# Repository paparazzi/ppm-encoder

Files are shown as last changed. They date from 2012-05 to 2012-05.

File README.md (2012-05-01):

ppm-encoder
===========

PPM Encoder board: http://paparazzi.enac.fr/wiki/ATmega_PPM_Encoder_Board

Author: hendrix (Chris Efstathiou)

Comments:  This software is FREE. Use it at YOUR OWN RISK.

PPM Encoder Hardware
--------------------
  - There are currently three revisions of the PPM Encoder board based around the ATMega168 mcu
  - The DIYDrones/3DRobotics version is an additional and different fourth hardware version based on this work
  - The code is/should be compatible with other ATMega8 series mcus, (known to work with the ATMega328)
  - The first board revision uses the internal RC oscillator of the mcu; this can cause timing accuracy issues
  - Later versions use an external 16MHz crystal/oscillator and provide cleaner, more stable output
  - Setting the fuses correctly for your hardware design is very important!

PPM Encoder Software
--------------------
  - The software is user configurable in the servo2ppm_settings.h file.
  - The software must be configured for the correct clock frequency and mcu in the makefile (or possibly the settings file).
  - The compiler for the software is avr-gcc.
  - Ideally, the software should be compiled using the version of avr-gcc included with WinAVR 2007 build 1221, available for download on sourceforge: http://sourceforge.net/projects/winavr/files/WinAVR/20071221/
  - Since this is windows software, you can run it on a windows box, a windows virtual machine or in wine (which seems to work fine). If using wine, call make with "wine" as a prefix: $ wine make (arguments).
  - The software can be easily loaded with avrdude using a supported programmer. Depending on which version you have, you may need to update avrdude.conf to include your mcu (i.e. if you have a 328).
  - There is a bootloader available if no programmer is available (but the bootloader will need to be loaded once with a programmer prior to use).
  - The fuses on your mcu must be carefully set. This can be done with avrdude. See below for correct fuse settings.

Fuse Settings
-------------
  - These settings may not work in all cases, depending on your board.
  - VERIFY BEFORE CHANGING FUSES ON YOUR MCU, OR YOU MAY BRICK IT! (especially the low fuse)
  - An online avr fuse calculator may help: http://www.engbedded.com/fusecalc
  - Low fuse has the same functions for the mega 328 and mega 168
  - High fuse sets sets the bootsize on 328 and the bodlevel in 168
  - Extended fuse sets the bodlevel only on 328 but it sets the bootsize on 168i
  - If you aren't using the bootloader, the fuses should still work fine, though feel free to disable the bootloader reset vector

**Low Fuse (same for 168 and 328, with or without bootloader):**
  - **0xDF** : 16Mhz External Oscillator (typically 0xFF on DIYDrones board)
  - **0xC2** : 8Mhz Internal RC Oscillator

**High Fuse:**
  - **0xDC** : for 168
  - **0xD8** : for 328

**Extended Fuse:**
  - **0xF8** : for 168
  - **0xFC** : for 328

**Note:** some numerical values refer to fuses containing undefined bits (set to '1' here). Depending on the target device these fuse bits will be read either as '0' or '1'. Verification errors will occur if the values are read back with undefined bits set to '0'.
 - For the 168: Everything is fine if the values read from the device are either the same as programmed, or the following values (undefined set to '0'): Extended: 0x00.
 - For the 328: Everything is fine if the values read from the device are either the same as programmed, or the following values (undefined set to '0'): Extended: 0x04

(Above note from http://www.engbedded.com/fusecalc)

Bootloader
----------
 - The bootloader is found in sw/bootloader.
 - To compile the bootloader, edit the MCU and F_CPU part of the makefile to match your hardware.
 - The memory offset will be automatically selected and assumes the fuses are set as described above
 - To compile the bootloader after editing the makefile:

    $ make

PPM Encoder
-----------
 - The ppm encoder source is found in sw/ppm_encoder.
 - Before compiling, edit the makefile for the appropriate clock frequency to match your hardware. You may also need to specify the path to the compiled bootloader .hex if you are trying to load the bootloader at the same time as the ppm encoder program.
 - To compile for the atmega328p (the makefile defaults to the 328):

    $ make

 - To compile for the atmega168:

    $ make mcu=atmega168

Uploading the Code
------------------

 - To upload the code to your board with a programmer, either directly call avrdude, or adjust the parameters in the makefile and call make program:

    $ avrdude -C /PATH/TO/ALTERNATE/avrdude.conf -c YOUR_PROGRAMMER_NAME -P YOUR_PROG_PORT -p YOUR_MCU -U flash:w:ppm_encoder_v4_3.hex:i

 - Check the avrdude help for more details and for how to check and write fuses (be careful). The makefile in sw/ppm_encoder can also be used to set fuses with make fuse_read to check and make fuse_write to set (make sure MCU and F_CPU are set correctly). The alternate avrdude.conf file might be needed if your version of avrdude does not have your mcu type defined (i.e. macports avrdude can direct to the Arduino 1.0 avrdude.conf if needed)

Some more example commands would be nice!

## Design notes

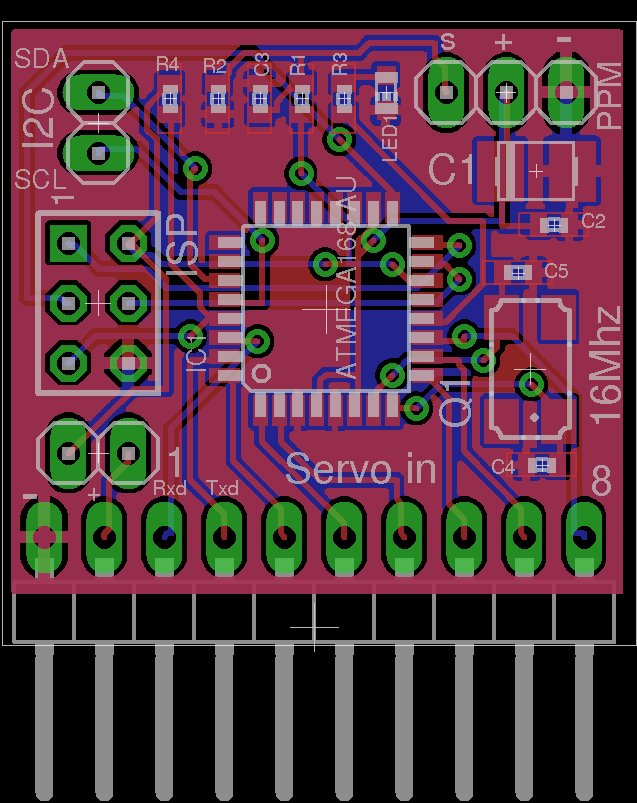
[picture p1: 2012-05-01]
hw/pcb_v3/ppm_encoder_crystal_v3.png

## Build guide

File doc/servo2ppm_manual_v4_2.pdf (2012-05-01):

# USER MANUAL

# PPM ENCODER BOARD

## (ATMEGA168)

### VERSION 4.2 (Firmware)

Created by Hendrix and Moa

3rd August 2009

### Table of Contents

JP1 JUMPER

FOR THOSE THAT MIGHT MAKE THE PPM ENCODER FROM SCRATCH:

FAILSAFE CONSIDERATIONS

THE PAPARAZZI “RADIO.XML" FILE

The places of interest for the “Bootloader procedure” are highlighted in Yellow on the

3rd August 2009 | 1

### INTRODUCTION

This software is FREE. Use it at your own risk.
This software and application comes without any guarantee of any kind.
You can modify the code and everything else as you please.

The whole project is based around the ATMEL ATMEGA168 AVR processor and all timing is done within interrupts so accuracy and stability is optimized
It is now also possible to select the PPM waveform shift, negative or positive.

Please use the above mentioned processor otherwise you may need to change/modify the source files of the project. The source code knows what chip you use from the device selected in the makefile.

Have in mind that the Paparazzi autopilot is a very complex system and you must pay attention to details

### OVERVIEW

You can use the throttle channel or any other channel to put the Paparazzi autopilot into "AUTO2" or “HOME” mode depending on the airframe settings.
This is effected by the PPM Encoder shutting down the PPM signal.

Basically you can connect any Rx channel to any PPM Encoder channel with the following provisions:

The RC receiver's throttle channel must be connected to channel 3 of the PPM Encoder as it is used as a rc signal lost indicator if the setup procedure has not be performed - otherwise any channel can be used if you execute the setup procedure

You can set the point where you want the PPM output to be turned off using the setup procedure else the default is that any servo pulse above ~2025 microseconds will shut down the PPM output thus force the Paparazzi autopilot into the "AUTO2" or “HOME” mode.

Make sure that your throttle channel's servo pulse does not exceed the PPM shut down threshold during normal operation by adjusting the EPA or whatever you call the servo travel limiter.
Only during loss of the RC signal when the receiver enters the failsafe mode should the throttle channel, or any other channel used as a Tx signal lost indication, be allowed to exceed this threshold (say 2100 microseconds).

The PPM board will cut the PPM output when the receiver goes into failsafe and set the throttle channel or any other channel if the setup procedure has been performed, to the extreme position.
This is done in order to simulate a traditional PPM receiver like the ones the Paparazzi designers used.

The extreme channel value used for indicating the signal loss to the PPM Encoder is not passed to the Paparazzi autopilot since the PPM output will be cut off when this extreme servo position is detected.

If the PPM board is set to continue to produce a PPM output, by not setting up the receiver to output this extreme servo position upon Tx signal loss means that your only option is to set the failsafe value of the receiver “MODE” channel to ”AUTO2” so the plane can enter the “AUTO2” mode
This method is not recommended for the following reasons:

If, upon loss of signal, all channels stay legitimate and the “MODE” channel indicates “AUTO2” then Paparazzi will enter “AUTO2” mode. Paparazzi will not be aware of the signal loss condition and will believe the pilot has com-manded the AUTO2 mode. Should the signal be reestablished with the Tx switch still in “Manual” mode then Paparazzi will faithfully switch to “MAN-UAL” mode with no pilot interaction.

Paparazzi, by design, manages the mode switching if it sees a loss of signal but with this configuration, the PPM Encoder hides the loss of signal so Paparazzi cannot manage mode switching safely.

Also be aware that some receivers failsafe due to low battery voltage (e.g.Futaba 7C) which can be reset (for 30 seconds) by selecting minimum throttle. Care must be exercised not to zero the throttle accidentally or pur-posely without considering the “MODE” switch. position. Again you could be put in command of the aircraft by a method other than using the “MODE” switch.

There are some receivers made by Futaba that output their servo pulses in a peculiar way.
One known Futaba Rx outputs the servo channels in the following order: 7,6,1,2,3,4,5
with channel 6 overlapping with channel 1. That should not cause any problem to the PPM encoder

Sometimes you may notice on some 2.4 Ghz systems that the ppm encoder takes some time
(1-3 seconds) to produce a PPM output.
This is because some 2.4 Ghz systems need to perform a hand shaking between the Transmitter and the receiver before they start producing a pulse at their throttle channel.

### FIRMWARE VERSIONS

RECEIVER TYPES AND THE PPM ENCODER BEHAVIOR

Version 3.8 firmware / Normal PPM receiver
The PPM Encoder will stop producing any PPM pulses when the Tx signal is lost thus setting the autopilot to "HOME" or "AUTO2" mode depending on the airframe settings.

Version 3.8 firmware / Receiver with failsafe settings on all channels
The user must set the failsafe for the "MODE" channel to 2000 microseconds so the autopilot can enter the "AUTO2" only mode when signal is lost.
This firmware is old and you should upgrade to version 4.00.

Version 3.9 firmware / Normal PPM Receiver
The PPM Encoder will stop producing any PPM pulses thus setting the autopilot the autopilot to "HOME" or "AUTO2" mode depending on the airframe settings.

Version 3.9 firmware / Receiver with failsafe settings on all channels or only the throttle channel. The user must make sure that the throttle channel will go above 2020 microseconds when the receiver looses the Tx signal but not during normal operation so when the receiver goes in to failsafe (loss of Tx signal) the PPM Encoder will cut the PPM output thus set the autopilot to "HOME" or "AUTO2" mode depending on the airframe settings.

Of course he can leave the throttle channel's failsafe setting to below 2000 microseconds and set the "MODE" channel's failsafe setting to 2000 microseconds thus force the autopilot in to "AUTO2" but this is not recommended.

Version 4.x firmware / Receiver with failsafe settings on all channels or only the throttle channel. The user must make sure that the throttle channel will go above 2025 microseconds when the receiver looses the Tx signal but not during normal operation so when the receiver goes into failsafe (loss of Tx signal) the PPM Encoder will cut the PPM output thus set the autopilot to "HOME" or "AUTO2" mode depending on the airframe settings.

In this version the user can also use a different than the throttle channel as a Tx lost indicator
and also setup the point where the PPM output will by cut off by using a simple setup procedure.

Of course he can leave the throttle channel's failsafe setting to below 2000 microseconds and set the "MODE" channel's failsafe setting to 2000 microseconds thus force the autopilot in to "AUTO2" but this is not recommended.

UNSUITABLE RECEIVERS

A receiver with no failsafe capabilities at least on the throttle channel (ch3) or also does not cut the servo pulses after a Tx signal loss but keeps the last good values is NOT SUITABLE FOR USE WITH THE PPM ENCODER.

### IMPORTANT THINGS TO WATCH FOR:

JP1 Jumper

The jumper JP1 has been included to provide some flexibility in the way you power the receiver, servos and PPM Encoder.

Often the power for the receiver, servos and PPM Encoder will come from the autopilot board. In this case JP1 should be in place.

If the receiver and any servos directly connected to the receiver get power from a separate/additional power source and the autopilot +5V is also connected to the PPM Encoder via the PPM connector - THEN YOU MUST REMOVE jumper JP1.
This will isolate the autopilot power supply from the separate receiver power supply.
Failure to remove JP1 will likely damage the autopilot's +5v switching regulator!

+5V provided
from autopilot+5V Not provided

from autopilot

Power supplied from Receiver and Servos Remove JP1JP1 in place

# Power NOT supplied from Receiver and Servos JP1 in place

For those that might make the PPM Encoder from scratch:

1. Before operating the PPM encoder, remember to clear the check mark for the

"CKDIV8" fuse. This is the only fuse that needs to be modified on a new ATMEGA168.
The ATMEGA168 is shipped with the internal oscillator selected as the clock source but with the "CKDIV8" fuse checked it is running at 1Mhz and not the 8Mhz we require.
2. If you decide to also use the bootloader make sure that you also check these three fuses:
1) BOOTRST, 2)BOOTSZ0, 3)BOOTSZ1.

Those 3 fuses tell the mcu to move the reset vector to the bootloader address and to reserve all 2048 bytes of bootloader memory space.

Failsafe considerations

1. When a receiver has failsafe mode this means that the servo pulses will not stop when the Tx signal is lost thus the encoder will always see valid servo signals
2. If you use a receiver with failsafe then remember to set the receiver's failsafe value for the throttle to above 2025 microseconds (2050 for example) so the PPM Encoder can simulate a traditional PPM receiver by shutting down the PPM signal.
You can alter the 2025 microsecond limit by executing the setup procedure.

Alternatively (not recommended, see above) set the "MODE" channel failsafe value to ~2000 microseconds so the autopilot can go to "AUTO2" mode when the received RC signal is lost or set.

3. If the receiver failsafe of the "MODE" channel is left at 1000 or 1500 microseconds and the throttle channel's failsafe setting does not exceed the 2025 microsecond limit then the aircraft is not protected and you will likely crash and loose the plane for the following reasons.
a) Paparazzi will stay in Manual mode because the MODE channel still commands this.
b) PPM Encoder will maintain a good PPM output and so Paparazzi will not enter AUTO2 or HOME mode as the signal is still considered good.
4. If the receiver only provides "hold" on the last good servo signal received it is not suitable for use with this encoder as it will prohibit the autopilot entering the "AUTO2" mode or initiate a lost signal condition by ceasing to pass a PPM signal to the autopilot.

This circuit was designed for use with:

a) Good quality receivers with full failsafe capabilities those days like the Multiplex IPD, the PCM range of receivers or the newer 2.4GHz ones.
b) Receivers that can be set to simply turn off the servo pulses when the Tx signal is lost
c) Simple PPM receivers that cannot maintain good servo pulses when reception is bad.

The Paparazzi “radio.xml" file

1. You must use a "radio.xml" file that contains 8 channels no matter how many channels your receiver has.

2. The PPM Encoder now dictates the number of channels and the PPM timing.
3. The reset_max value inside the radio.xml file should be more than 13000 microseconds.
Here is an example of a working "radio.xml" file for my Royal Evo 12 and my MC4000 with the "MODE" channel being channel 7:

<!DOCTYPE radio SYSTEM "radio.dtd">
<radio name="RE12" data_min="800" data_max="2200" sync_min="5000" sync_max="15000"> <channel ctl="C" function="ROLL" min="950" neutral="1500" max="2050" average="0"/> <channel ctl="B" function="PITCH" min="950" neutral="1500" max="2050" average="0"/> <channel ctl="D" function="THROTTLE" min="950" neutral="950" max="2050" average="0"/> <channel ctl="A" function="YAW" min="950" neutral="1500" max="2050" average="0"/> <channel ctl="E" function="FLAPS" min="950" neutral="1500" max="2050" average="0"/> <channel ctl="F" function="GAIN1" min="950" neutral="1500" max="2050" average="1"/> <channel ctl="G" function="MODE" min="950" neutral="1500" max="2050" average="1"/> <channel ctl="H" function="GAIN2" min="950" neutral="1500" max="2050" average="1"/> </radio>

If you want the "MODE" channel to be channel 5 just change the order of the lines:

<!DOCTYPE radio SYSTEM "radio.dtd">
<radio name="RE12" data_min="800" data_max="2200" sync_min="5000" sync_max="15000"> <channel ctl="C" function="ROLL" min="950" neutral="1500" max="2050" average="0"/> <channel ctl="B" function="PITCH" min="950" neutral="1500" max="2050" average="0"/> <channel ctl="D" function="THROTTLE" min="950" neutral="950" max="2050" average="0"/> <channel ctl="A" function="YAW" min="950" neutral="1500" max="2050" average="0"/> <channel ctl="G" function="MODE" min="950" neutral="1500" max="2050" average="1"/> <channel ctl="E" function="FLAPS" min="950" neutral="1500" max="2050" average="0"/> <channel ctl="F" function="GAIN1" min="950" neutral="1500" max="2050" average="1"/> <channel ctl="H" function="GAIN2" min="950" neutral="1500" max="2050" average="1"/> </radio>
4. If you want you can change the channel assignment of your Tx or Rx at anytime. Just make sure that the channel functions, as they are connected at the PPM Encoder, match the order in the radio.xml file.

An example:
Say you have an eight channel receiver that has channels 1,2,3,4,8 connected to the PPM Encoder with channel 8 being the "MODE" channel and suddenly you want to swap the receiver with a 6 channel one. You now don’t have a receiver channel 8 but the solution is very simple.
- You must connect channels 1,2,3,4 as before
- Connect any one of the remaining channels (say Rx channel 5) to channel 8 of the PPM encoder.

- You next assign the "MODE" switch on your transmitter to channel 5.
- You should not change anything in the radio.xml file as servo position 8 on the PPM Encoder was already known to be the MODE channel by Paparazzi.

The PPM Encoder dictates the channel order you see in the "radio.xml" file and not the receiver servo channels. If, as in the above example, channel 5 of the receiver is the "MODE" channel and this channel is connected to servo connector/position 8 of the PPM encoder, then Paparazzi autopilot will see the "MODE" channel as being channel 8 no matter what channel you use at your transmitter or receiver side.

5. The PPM Encoder is built to output a Futaba style PPM signal which differs from that of all other brands including JR. Paparazzi must be set to expect a Futaba style PPM signal.
- Locate the following line in the airframe file (correct)
"ap.CFLAGS += -DRADIO_CONTROL -DRADIO_CONTROL_TYPE=RC_FUTABA"

If your definition reads as follows (incorrect)
"ap.CFLAGS += -DRADIO_CONTROL -DRADIO_CONTROL_TYPE=RC_JR " modify it to be the same as the correct line above with FUTABA in place of JR.

Alternatively you can set the definition "RC_PPM_OUTPUT_TYPE" to 1.

It does not matter what make of receiver or transmitter you have since the PPM Encoder controls all parameters of the PPM waveform.

### HOW TO TEST THE BOARD

Here we test that the PPM Encoder is basically working.

Refer to the image of the board for the points referred to in this “How to test the Board” procedure”. They are highlighted in Magenta .

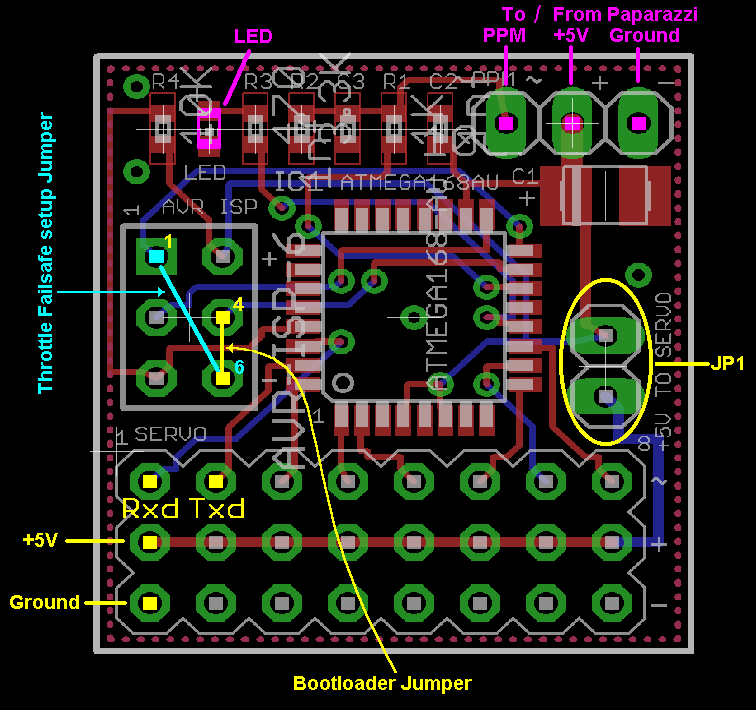
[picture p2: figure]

For this test you may initially leave the "MODE" channel of the receiver disconnected from the PPM Encoder. It can be connected later during the procedure.

SAFETY FIRST

- Start with all airplane and Tx power off
- Ensure the JP1 jumper is set correctly as per “IMPORTANT THINGS TO WATCH FOR”

REMOVE THE PROPELLER OR DICONNECT THE MOTOR CABLES !!!

- Connect the encoder to the receiver and autopilot.
Please verify the integrity of all connections to the autopilot and from the receiver to the PPM Encoder board. The PPM output pin header has the ground near the PCB corner, the positive 5 volts to the middle pin and the PPM output is the pin near the 402 sized components (C2, R1, C3 etc.).
- Power up the airplane with the Tx powered off.
The LED should be on constantly without blinking.
- Power On the RC transmitter
The LED should start to blink with a rate 3 times per second (that is 3Hz)
The LED blinking at 3Hz means that the internal timing is correct, that the board sees all of the incoming receiver servo pulses and that the PPM waveform generator is on and working.
- Confirm that the servos move when you move the sticks.
- Next disconnect a channel from the receiver (just unplug it) and see if the led blinks slower now at 1 time per second (1Hz).
That means that one or more of the servo signals are lost and that the PPM output is off.
- Now remove power from the plane, connect the “MODE” channel from the RC receiver to the PPM Encoder board if you haven't done it already.
- Ensure you have assigned the Transmitter Mode switch to the appropriate channel.
- Power on the RC transmitter again first and then the airplane.
The PPM encoder's led should blink fast at a rate of ~3Hz and you should be able to switch between “MANUAL', “AUTO1' and “AUTO2” using the RC transmitter's switch that you have assigned to be the mode change switch.

You can tell in what mode you are in by looking at the GCS screen.

VERY IMPORTANT

The following test ensures the PPM Encoder stops the PPM signal when a failsafe receiver goes into failsafe.
(You can perform this test later if you are going to use the THROTTLE FAILSAFE SETUP procedure)
- Switch to “MANUAL” mode
- Move the throttle stick to:
a. Minimum if you have a Futaba transmitter
b. Maximum for all other transmitter brands
c. To the side you selected during the “THROTTLE FAILSAFE SETUP” if you have performed it.
- Adjust the EPA of this throttle stick's side to maximum so the led changes it's blinking rate from 3Hz to 1Hz when you move the throttle stick to the extreme min or max position depending on what brand you have.
- Set this position as the receiver failsafe position for the throttle channel.
You will be able to see the led changing it's flashing rate when you move the throttle stick.
- Now return the EPA to normal in order to make sure that this extreme throttle servo pulse cannot occur during normal operation but only when the receiver goes in to failsafe.

The above steps are required in order to make the PPM Encoder simulate a traditional PPM receiver. The PPM board will cut the PPM output when the receiver goes into failsafe and moves the throttle channel to the extreme position (past 2020 microseconds) exactly like a traditional PPM receiver would.

### HOW TO ENTER THE THROTTLE FAILSAFE SETUP

Here we set up the Throttle Failsafe value. The PPM Encoder is being taught a throttle channel pulse width that, beyond which, will indicate that the Rx is in failsafe mode.

Refer to the image of the board for the points referred to in this procedure”.
They are highlighted in Cyan

If you want to set a channel other than the throttle channel to be the Tx signal lost indicator then you must disconnect all other receiver channels except the desired one from the PPM Encoder and then proceed to complete the setup procedure described below.

If only one channel of the receiver is connected to the PPM Encoder during power up for the setup procedure, then this channel is selected as the Tx signal lost indicator and the PPM shut down threshold can be adjusted for this channel. It can be any channel you want.

If more than one channel of the receiver is connected to the PPM Encoder during power up for the setup procedure then the default channel will be used. This is the Throttle Channel (#3 of the PPM encoder) with a threshold of 2025 microseconds.

This is done in order to enable the user to execute the setup procedure with out disconnecting
the ppm encoder from the system if the default setting of using channel 3 (the throttle channel)
is acceptable.

SAFETY FIRST

- Remove power from the plane
- Ensure the JP1 jumper is set correctly as per “IMPORTANT THINGS TO WATCH FOR”

REMOVE THE PROPELLER OR DICONNECT THE MOTOR CABLES !!!

- Ground pin 1 of the ISP header (Connect Pin 1 to Pin 6 of the ISP header) using a small piece of wire with 2 female pin connectors.
- Stop! ……Do not power up the plane and the PPM board just yet.
- Power up the transmitter

Make sure that the throttle EPA for the throttle side you select in the next step is not set to maximum because you will need a little extra later on (about 7% more). The actual threshold will be set at 25 microseconds above the recorded value if the value recorded was above 1500 microseconds or 25 microseconds below the recorded value if the value recorded was below 1500 microseconds.

In other words the threshold where the PPM output is cut off will be set 25 microseconds above or below the recorded value depending which side of the throttle stick you have selected.

- Set the throttle stick to the end position you want, say at the min throttle position.
This position will be set as the extreme value that can happen during normal operation.
A bit beyond this position is the value you will subsequently set into the Receiver as the failsafe setting
- Then power up the PPM board by connecting the battery to the airplane.
The LED on the PPM board will light solid and when the setup is finished it will start to flash with 1Hz rate and a duty cycle of:
- 100ms ON – 900ms OFF if the setup is successful and with a rate of 1Hz
- 900ms ON – 100ms OFF duty cycle (almost solid on) if the setup failed
(the opposite of when the setup was successful).

If the setup failed (highly unlikely) then check the connections and repeat the setup procedure after a power cycle.

- If the setup was successful then remove power from the PPM board
- Remove the grounding connector from pin 1 of the ISP header.
- Power up again normally, you should see the led flash at 3Hz as usual.
- Test to see if the LED changes it's blinking frequency to 1Hz by adjusting the transmitter throttle EPA of the side you selected during setup to maximum and then moving the throttle stick to the end point you had selected during the setup procedure.
The LED should change it's blinking frequency to 1Hz
- Move the throttle stick back towards the center again.
The LED should change it's blinking frequency back to 3Hz
- Next set this extreme position (the LED should blink with 1 Hz rate) as the receiver failsafe position for the throttle channel.
- Now return the EPA to normal in order and make sure that this extreme throttle servo pulse cannot occur during normal operation. (3Hz blinking at all Throttle positions)
- Finally check that the PPM board changes the led frequency to 1Hz when you switch off the transmitter thus forcing the receiver to enter the failsafe mode.

The above steps are required in order to make the PPM Encoder simulate a traditional PPM receiver. The PPM board will cut the PPM output exactly like a traditional PPM receiver would when a failsafe capable receiver goes into failsafe and moves the throttle channel to the extreme position.

If you do not perform this setup procedure then the default value will be used which is to cut the PPM output when the throttle channel's servo pulse goes above 2025 microseconds.

You can change the default value defined in the “servo2PPM_settings.h” file to suit your needs
but you will need to recompile the source code of the PPM Encoder.

### ABOUT THE BOOTLOADER

The whole project is based around the ATMEL AVR processor and specifically the ATMEGA168. Please use the above mentioned processor otherwise you may need to change/modify the source files of the project.
I have tested the bootloader with other processors and it worked well right out of the box but I can't guarantee anything.
If you want to use the bootloader (recommended so later you can update the firmware without using an AVR programmer) you can use the "app+bootloader.hex" file to flash both the servo2PPM and the bootloader code at once. Alternatively you can first flash the the PPM_encoder_ver_x_x.hex file with the "erase chip before flashing" option of the avrstudio flashing utility turned on and then flash the "bootloader.hex file but this time with the "erase chip before flashing" option turned off
(ie do not erase the chip before you flash the "bootloader.hex" file).
- NOTE: Read carefully the later section from the Mega168 datasheet on Boot Lock Bits.

BEFORE ENTERING THE BOOTLOADER DISCONNECT EVERYTHING FROM THE PPM ENCODER BOARD !!!

The places of interest for the “Bootloader procedure” are highlighted in | Yellow | on the board image
- Make sure that everything (receiver, tiny or TWOG) is disconnected from the PPM Encoder board including power
- Place a jumper between pin 4 and pin 6 (ground) of the ISP header.
- Prepare the FTDI cable
The +5 volts that will power the PPM Encoder board will come from the +5 volts of the FTDI cable so you need to make a cable that will connect the FTDI's +5v,Rxd,Txd and Ground to the PPM encoder's +5v, Rxd, Txd and Ground.

The +5 volts and Ground of the FTDI cable are connected to any of the PPM Encoder board’s servo input +5 volt and ground pins.

The serial pins for connecting the FTDI cable to the PPM Encoder board are the signal pins of servos 1 and 2 . Servo1=Rxd, Servo2=Txd as depicted on the picture of the board.

- NOTE: these must be connected crossed to the FTDI cable
ie. Servo 1 signal pin to FTDI Txd and servo 2 signal pin to FTDI Rxd.
- You can then reset the PPM Encoder board as needed by removing the jumper JP1 that is normally used to feed power to the servo header.
- Wait for ~2 seconds and replace the jumper again on JP1 in order to restore power to the board.

In order to upload the file needed, reset the PPM Encoder board by power cycling it making sure that the connection with the terminal program like "HyperTerminal is already opened and connected
at 9600 bps 8 bits, no parity, 1 stop bit, no flow control and carriage return (CR) as terminator of the line.
After power cycling (reset) the PPM Encoder board you should see the prompt "ATH=help >" on your screen.
- Type "ATWF" using capital or small or mixed letters and hit enter.
Now the "C" character will start to fill the screen which means that you must start the X modem CRC transfer from your terminal program.
- Select the Xmodem type of file transfer, then select the file to be uploaded ("PPM_encoder_ver_x_x.bin") and click the send button or whatever your terminal program uses.
Be carefull "Xmodem 1K" IS NOT THE SAME!!!
Usually “Xmodem CRC” is referred as plain "Xmodem".

Then the transfer window of your program will show up telling you the transfer progress and after the transfer is hopefully complete and successful the window will automatically close and you will
see the message “update successful” at the terminal 's screen.

The bootloader commands are:

ATWF = write flash.
ATWE = write Eeprom.
ATI = Display version information about the bootloader and the PPM Encoder firmware ATRB = Read boot lock fuses.
ATRL = Read the low fuses.
ATRH = Read the high fuses.
ATRE = Read the extended fuses.
ATWB = Write or modify the boot lock fuses

For the PPM Encoder firmware version to be displayed using the “ATI” command the PPM Encoder firmware must run at least once in order to register it's version info into the EEPROM.
That means that if you want to be absolutely sure which version you are about to use after a firmware upgrade then
- power off
- remove the jumper from pins 4 and 6 of the ISP header,
- power on again so the PPM Encoder software can run (No need to connect anything to the PPM Encoder board)
- power off the board, install the jumper to pins 6 and 4 and power on again.
Now the “ATI” command will show something like "Servo2PPM V4.00".

Pay particular attention to the ATWB command as it can render the PPM Encoder useless and then only a flash erase and programming of the board again will make the PPM Encoder work again.

The fuse bytes are presented with binary form for example 00000010 = 2

If you attempt to modify the boot lock fuses you need to issue a command like this: ATWB11111011 + ENTER

The above command will program the BLB02 fuse.

I recommend to leave the boot lock bits as they are and not play with the “ATWB” command at all as the bootloader code is already protecting the bootloader's flash memory space.

### SETTING THE BOOT LOCK BITS

USING THE ATWLxxxxxx BOOTLOADER COMMAND.
BOOT LOCK BIT programming (BLB12, BLB11, BLB02, BLB01, LB2 and LB1)

To set the Boot Loader Lock bits and General Lock bits using the bootloader first examine the table below.

Enter the command ATWLxxxxxx and press enter.
The xxxxxx are the binary presentation of lockbits 5,4,3,2,1 and 0 Bits 7 and 6 are omitted since you cannot program them.

Examples

ATWL11011111
= the boot lock bit 5 will be programmed (BLB12)

ATWL1111101
= the boot lock bit 1 will be programmed (LB2)

ATWL1111110
= the boot lock bit 0 will be programmed (LB1)

So if bits 5..0 in R0 are cleared (zero), the corresponding Boot Lock bit or General Lock bit will be programmed.

“1” means not programmed, “0” means programmed

Be careful with the boot lock bits.

BOOT LOCK PROTECTION MODE TABLES
Below are two tables with the functionality of the boot lock bits of the ATMEGA168.

Boot Lock Bit0 Protection Modes (Application Section)(1)

Table 26-2.
BLB0 Mode | BLB02 | BLB01 | Protection
1 | 1 | 1 | No restrictions for SPM or LPM accessing the Application section.
2 | 1 | 0 | SPM is not allowed to write to the Application section.
3 | 0 | 0 | SPM is not allowed to write to the Application section, and LPM executing from the Boot Loader section is not allowed to read from the Application section. If Interrupt Vectors are placed in the Boot Loader section, interrupts are disabled while executing from the Application section.
4 | 0 | 1 | LPM executing from the Boot Loader section is not allowed to read from the Application section. If Interrupt Vectors are placed in the Boot Loader section, interrupts are disabled while executing from the Application section.

Boot Lock Bit1 Protection Modes (Boot Loader Section)(1)

Table 26-3.
BLB1 Mode | BLB12 | BLB11 | Protection
1 | 1 | 1 | No restrictions for SPM or LPM accessing the Boot Loader section.
2 | 1 | 0 | SPM is not allowed to write to the Boot Loader section.
3 | 0 | 0 | SPM is not allowed to write to the Boot Loader section, and LPM executing from the Application section is not allowed to read from the Boot Loader section. If Interrupt Vectors are placed in the Application section, interrupts are disabled while executing from the Boot Loader section.
4 | 0 | 1 | LPM executing from the Application section is not allowed to read from the Boot Loader section. If Interrupt Vectors are placed in the Application section, interrupts are disabled while executing from the Boot Loader section.

Note: 1. “1” means un-programmed, “0” means programmed

Have fun.
Chris

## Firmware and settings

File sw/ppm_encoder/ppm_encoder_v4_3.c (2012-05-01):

/*********************************************************************************************************
 Title  :   C  file for the rc ppm encoder (servo2ppm_v4_3.c)
 Author:    Chris Efstathiou
 E-mail:    hendrix at vivodinet dot gr
 Homepage:  ........................
 Date:      07/Feb/2010
 Compiler:  AVR-GCC with AVR-AS
 MCU type:  ATmega168
 Comments:  This software is FREE. Use it at your own risk.
*********************************************************************************************************/


/********************************************************************************************************/
/*                                   PREPROCESSOR DIRECTIVES                                            */
/********************************************************************************************************/


#include <avr/io.h>
#include <avr/interrupt.h>
#include <avr/wdt.h>
#include <avr/eeprom.h>
#include <inttypes.h>
#include "servo2ppm_settings.h"




/********************************************************************************************************/
/*             Normaly you shouldn't need to change anything below this line but who knows?             */
/********************************************************************************************************/

#if defined(__AVR_ATmega168__) || defined(__AVR_ATmega328P__)

#define RC_SERVO_PORT                 D   /* The port for the servo pulse input. */

#define RC_LED_PORT                   B  /* The port for the PPM waveform and the led. */
#define RC_LED_PIN                    0  /* The led indicator pin. */

#define RC_PPM_PORT                   B
#define RC_PPM_PIN                    2  /* The PPM waveform output pin */

#define RC_SETUP_PORT                 B
#define RC_SETUP_PIN                  4

#define RC_TIMER0_TIMSK               TIMSK0 /* Timer0 registers */
#define RC_TIMER0_TIFR                TIFR0
#define RC_TIMER0_PRESCALER_REG       TCCR0B

#define RC_TIMER1_TIMSK               TIMSK1 /* Timer1 registers */
#define RC_TIMER1_TIFR                TIFR1
#define RC_TIMER1_PRESCALER_REG       TCCR1B
#define RC_TIMER1_MODE_REG            TCCR1A
#define RC_TIMER1_COMP1_REG           OCR1A
#define RC_TIMER1_COMP2_REG           OCR1B

#define RC_PIN_INT_EN_REG             PCICR
#define RC_PIN_INT_EN_BIT             PCIE2
#define RC_PIN_INT_FLAG_REG           PCIFR
#define RC_PIN_INT_FLAG_BIT           PCIF2
#define RC_PIN_INT_MASK_REG           PCMSK2

#define RC_SERVO_INPUT_CHANNELS       8

#else
/*
You can copy the above avr type data and edit them as needed if you plan to use
a different avr type cpu having at least 2k bytes of flash memory.
*/

#error AVR type not suitable
#endif

#define _CONCAT2_(a, b)               a ## b
#define CONCAT2(a, b)                 _CONCAT2_(a, b)

#define RC_SERVO_PORT_OUT_REG         CONCAT2(PORT, RC_SERVO_PORT)
#define RC_SERVO_PORT_DDR_REG         CONCAT2(DDR,  RC_SERVO_PORT)
#define RC_SERVO_PORT_PIN_REG         CONCAT2(PIN,  RC_SERVO_PORT)

#define RC_LED_PORT_OUT_REG           CONCAT2(PORT, RC_LED_PORT)
#define RC_LED_PORT_DDR_REG           CONCAT2(DDR,  RC_LED_PORT)
#define RC_LED_PORT_PIN_REG           CONCAT2(PIN,  RC_LED_PORT)

#define RC_PPM_PORT_OUT_REG           CONCAT2(PORT, RC_PPM_PORT)
#define RC_PPM_PORT_DDR_REG           CONCAT2(DDR,  RC_PPM_PORT)
#define RC_PPM_PORT_PIN_REG           CONCAT2(PIN,  RC_PPM_PORT)

#define RC_SETUP_PORT_OUT_REG         CONCAT2(PORT, RC_SETUP_PORT)
#define RC_SETUP_DDR_REG              CONCAT2(DDR,  RC_SETUP_PORT)
#define RC_SETUP_PIN_REG              CONCAT2(PIN,  RC_SETUP_PORT)


#if RC_PPM_GEN_CHANNELS > 8
#error PPM generator max number of channels is 8
#endif
#if RC_PPM_GEN_CHANNELS == 0
#error PPM generator channels cannot be zero!
#endif

#if RC_PPM_GEN_CHANNELS < RC_SERVO_INPUT_CHANNELS
#undef RC_SERVO_INPUT_CHANNELS
#define RC_SERVO_INPUT_CHANNELS   RC_PPM_GEN_CHANNELS
#warning servo channels = PPM generator channels
#endif

#if RC_PPM_RESET_PW == 0 && RC_PPM_FRAME_LENGTH_MS == 0

#undef RC_PPM_FRAME_LENGTH_MS
#undef RC_PPM_RESET_PW
#define RC_PPM_RESET_PW              5500UL
#define RC_PPM_FRAME_LENGTH_MS       (RC_PPM_RESET_PW + (RC_PPM_GEN_CHANNELS * RC_SERVO_CENTER_PW))

#elif RC_PPM_FRAME_LENGTH_MS == 0 && RC_PPM_RESET_PW > 0

#undef RC_PPM_FRAME_LENGTH_MS
#define RC_PPM_FRAME_LENGTH_MS       ((RC_PPM_GEN_CHANNELS * RC_SERVO_MAX_PW)+RC_PPM_RESET_PW)

#elif RC_PPM_FRAME_LENGTH_MS > 0 && RC_PPM_RESET_PW == 0

#undef RC_PPM_RESET_PW
#define RC_PPM_RESET_PW              (RC_PPM_FRAME_LENGTH_MS -(RC_PPM_GEN_CHANNELS * RC_SERVO_MAX_PW))

#endif

#if RC_PPM_FRAME_LENGTH_MS > 25000UL
#warning PPM frame period exceeds 25ms
#endif

#if RC_PPM_RESET_PW <= (5000UL + RC_PPM_CHANNEL_SYNC_PW)
#warning PPM reset period lower than 5ms
#endif


/* Search for a suitable timer prescaler. Both timers must use the same prescaler factor. */
#if  ((F_CPU * (RC_MAX_TIMEOUT/1000))/1000) < 0xFFF0

#define TIMER0_PRESCALER   1
#define TIMER0_PRESCALER_BITS   ((0<<CS02)|(0<<CS01)|(1<<CS00))
#warning TIMER0 PRESCALER SET TO 1

#elif  (((F_CPU * (RC_PPM_FRAME_TIMEOUT/1000))/1000)/8) < 0xFFF0

#define TIMER0_PRESCALER   8
#define TIMER0_PRESCALER_BITS   ((0<<CS02)|(1<<CS01)|(0<<CS00))
#warning TIMER0 PRESCALER SET TO 8

#elif  (((F_CPU * (RC_PPM_FRAME_TIMEOUT/1000))/1000)/64) < 0xFFF0

#define TIMER0_PRESCALER   64
#define TIMER0_PRESCALER_BITS   ((0<<CS02)|(1<<CS01)|(1<<CS00))
#warning TIMER0 PRESCALER SET TO 64

#endif

#define TIMER1_PRESCALER    TIMER0_PRESCALER

#if TIMER1_PRESCALER == 1

#define TIMER1_PRESCALER_BITS   ((0<<CS12)|(0<<CS11)|(1<<CS10))
#warning TIMER1 PRESCALER SET TO 1

#elif  TIMER1_PRESCALER == 8

#define TIMER1_PRESCALER_BITS   ((0<<CS12)|(1<<CS11)|(0<<CS10))
#warning TIMER1 PRESCALER SET TO 8

#elif  TIMER1_PRESCALER == 64

#define TIMER1_PRESCALER_BITS   ((0<<CS12)|(1<<CS11)|(1<<CS10))
#warning TIMER1 PRESCALER SET TO 64

#else

#error NO SUITABLE PRESCALER FOR TIMER1 FOUND!

#endif

/* Now that the timer prescalers are known the conversion of microseconds to timer values follows */
#define RC_SERVO_CENTER_PW_VAL          ((((F_CPU/1000) * RC_SERVO_CENTER_PW )/1000)/TIMER0_PRESCALER)
#define RC_SERVO_MIN_PW_VAL             ((((F_CPU/1000) * RC_SERVO_MIN_PW)/1000)/TIMER0_PRESCALER)
#define RC_SERVO_MAX_PW_VAL             ((((F_CPU/1000) * RC_SERVO_MAX_PW)/1000)/TIMER0_PRESCALER)

#define RC_PPM_OFF_THRESHOLD_VAL        ((((F_CPU/1000) * RC_LOST_THRESHOLD)/1000)/TIMER0_PRESCALER)
#define RC_PPM_OFF_UPPER_WINDOW_VAL     ((((F_CPU/1000) * 1700)/1000)/TIMER0_PRESCALER) //1700 microseconds
#define RC_PPM_OFF_LOWER_WINDOW_VAL     ((((F_CPU/1000) * 1300)/1000)/TIMER0_PRESCALER) //1300 microseconds
#define RC_PPM_OFF_OFFSET_VAL           ((((F_CPU/1000) * RC_THROTTLE_CH_OFFSET_PW)/1000)/TIMER0_PRESCALER)

#define RC_MAX_TIMEOUT_HI_8_VAL         ((((((F_CPU/1000) * RC_MAX_TIMEOUT)/1000)/TIMER0_PRESCALER)/256)+1)
#define RC_MAX_PULSE_TIMEOUT_HI_8_VAL   ((((((F_CPU/1000) * RC_SERVO_MAX_PW)/1000)/TIMER0_PRESCALER)/256)+1)
#define RC_MIN_PULSE_TIMEOUT_HI_8_VAL   ((((((F_CPU/1000) * RC_SERVO_MIN_PW)/1000)/TIMER0_PRESCALER)/256)+1)

#define RC_PPM_FRAME_TIMER_VAL          ((((F_CPU/1000) * RC_PPM_FRAME_LENGTH_MS)/1000)/TIMER1_PRESCALER)
#define RC_PPM_SYNC_PW_VAL              ((((F_CPU/1000) * RC_PPM_CHANNEL_SYNC_PW)/1000)/TIMER1_PRESCALER)

#define RC_FS_CH_1_TIMER_VAL            ((((F_CPU/1000) * RC_FAILSAFE_CHANNEL_1)/1000)/TIMER1_PRESCALER)
#define RC_FS_CH_2_TIMER_VAL            ((((F_CPU/1000) * RC_FAILSAFE_CHANNEL_2)/1000)/TIMER1_PRESCALER)
#define RC_FS_CH_3_TIMER_VAL            ((((F_CPU/1000) * RC_FAILSAFE_CHANNEL_3)/1000)/TIMER1_PRESCALER)
#define RC_FS_CH_4_TIMER_VAL            ((((F_CPU/1000) * RC_FAILSAFE_CHANNEL_4)/1000)/TIMER1_PRESCALER)
#define RC_FS_CH_5_TIMER_VAL            ((((F_CPU/1000) * RC_FAILSAFE_CHANNEL_5)/1000)/TIMER1_PRESCALER)
#define RC_FS_CH_6_TIMER_VAL            ((((F_CPU/1000) * RC_FAILSAFE_CHANNEL_6)/1000)/TIMER1_PRESCALER)
#define RC_FS_CH_7_TIMER_VAL            ((((F_CPU/1000) * RC_FAILSAFE_CHANNEL_7)/1000)/TIMER1_PRESCALER)
#define RC_FS_CH_8_TIMER_VAL            ((((F_CPU/1000) * RC_FAILSAFE_CHANNEL_8)/1000)/TIMER1_PRESCALER)
#define RC_RESET_PW_TIMER_VAL           ((((F_CPU/1000) * RC_PPM_RESET_PW)/1000)/TIMER1_PRESCALER)

#if F_CPU <= 8000000UL
#define  RC_NUMBER_OF_SAMPLES           6
#else
#define  RC_NUMBER_OF_SAMPLES           4
#endif


//#define RC_TIMER0_VAL_CORRECTION        ((RC_SERVO_CENTER_PW_VAL *100)/RC_SERVO_CENTER_PW )

/* Some error checking */
/* The timer can only count up to 65535 so the high byte can go up to 255 */
#if (RC_MAX_TIMEOUT_HI_8_VAL  > 254)
#error RC_MAX_TIMEOUT  is set too high!
#endif

//It is used when there is no servo signals received so the elapsed time is always RC_MAX_TIMEOUT ms.
//In case the watchdog timer is used then the elapsed time is always the wdt timeout.
#define RC_LED_FREQUENCY_VAL_4HZ	(((1000000/4)/25000)/2)
#if F_CPU <= 8000000UL
#define RC_LED_FREQUENCY_VAL_1HZ	(((1000000/1)/60000)/2)
#else
#define RC_LED_FREQUENCY_VAL_1HZ	(((1000000/1)/30000)/2)
#endif



/* Macro command definitions. */
#define LED_ON()                        { RC_LED_PORT_OUT_REG |= (1<<RC_LED_PIN); }
#define LED_OFF()                       { RC_LED_PORT_OUT_REG &= (~(1<<RC_LED_PIN)); }
#define TOGGLE_LED()                    { RC_LED_PORT_OUT_REG ^= (1<<RC_LED_PIN); }

#define STOP_TIMER0()                   { RC_TIMER0_PRESCALER_REG = 0; }
#define START_TIMER0()                  { RC_TIMER0_PRESCALER_REG = TIMER0_PRESCALER_BITS; }
#define RESET_TIMER0()                  { RC_TIMER0_TIFR |= (1<<TOV1); TCNT0=0; timer0_h8=0; timer0_h8_buf=0; }
#define RESET_START_TIMER0()            { STOP_TIMER0(); RESET_TIMER0(); START_TIMER0(); }

#if RC_USE_FAILSAFE > 1
#error RC_USE_FAILSAFE can be 0 or 1
#endif
#if RC_PPM_OUTPUT_TYPE > 1
#error RC_PPM_OUTPUT_TYPE can be 0 or 1
#endif
#if RC_CONSTANT_PPM_FRAME_TIME > 1
#error RC_CONSTANT_PPM_FRAME_TIME can be 0 or 1
#endif
#if RC_REDUCE_LATENCY > 2
#error RC_REDUCE_LATENCY can be 0, 1 or 2
#endif


/********************************************************************************************************/
/*                                   TYPE DEFINITIONS                                                   */
/********************************************************************************************************/







/********************************************************************************************************/
/*                                   LOCAL FUNCTION PROTOTYPES                                          */
/********************************************************************************************************/
void initialize_mcu(void);
void wait_for_rx(void);
unsigned char detect_connected_channels(void);
unsigned int get_channel_pw(unsigned char pin);
void check_for_setup_mode(void);
void write_default_values_to_eeprom(void);
void load_failsafe_values(void);
void load_values_from_eeprom(void);
static inline void ppm_off(void);
static inline void ppm_on(void);
void get_pw_of_connected_channels(unsigned char reset);




/********************************************************************************************************/
/*                                   GLOBAL VARIABLES                                                   */
/********************************************************************************************************/

volatile unsigned int   isr_channel_pw[(RC_PPM_GEN_CHANNELS +1)]; // +1 is for the reset pulse.
/*
unsigned int            fs_channel_pw[8]= { RC_FS_CH_1_TIMER_VAL, RC_FS_CH_2_TIMER_VAL,
                                            RC_FS_CH_3_TIMER_VAL, RC_FS_CH_4_TIMER_VAL,
                                            RC_FS_CH_5_TIMER_VAL, RC_FS_CH_6_TIMER_VAL,
                                            RC_FS_CH_7_TIMER_VAL, RC_FS_CH_8_TIMER_VAL,
                                          };
*/
#if (__GNUC__ == 4 && __GNUC_MINOR__ == 2)

register volatile unsigned char  timer0_l8 asm("r2");
register volatile unsigned char  timer0_h8 asm("r3");
register volatile unsigned int   isr_time_stamp asm("r4");
register volatile unsigned char  pin_interrupt_detected asm("r6");
register volatile unsigned char  sreg_save asm("r7");
register volatile unsigned char  isr_channel_number asm("r8");
register volatile unsigned char  channel_mask_buffer asm("r9");
register volatile unsigned char  pin_reg_buffer0 asm("r10");
register volatile unsigned char  pin_reg_buffer1 asm("r11");

#else
#warning GCC versions greater than 4.2.x have optimization problems with register variables.
#warning No register variables are used.

volatile unsigned char  timer0_l8 = 0 ;
volatile unsigned char  timer0_h8 = 0 ;
volatile unsigned int   isr_time_stamp = 0;
volatile unsigned char  pin_interrupt_detected = 0;
volatile unsigned char  isr_channel_number = 0;
//volatile unsigned char  isr_pin_reg_buf = 0;
volatile unsigned char  channel_mask_buffer = 0;

#endif
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
__attribute__((noreturn)) void main(void)
{

//Variables for the PPM control code.
unsigned char  tx_signal_lost = 0;
unsigned char  tx_signal_detected = 0;
unsigned char  led_frequency = 0;
unsigned char  led_counter = 0;

wdt_disable();
wdt_enable(WDTO_500MS);
wdt_reset();

initialize_mcu();
/*Load the values stored in the eeprom like the throttle channel threshold etc. */
load_values_from_eeprom();
//Load the ISR array. This way if a channel is not connected it will have the failsafe value.
load_failsafe_values();
/*
The "wait_for_rx(): function waits untill the receiver has been powered up and running
so we can then detect the connected channels with certainty.
*/
wait_for_rx();
channels_in_use = detect_connected_channels();
check_for_setup_mode();
servo_signals_lost = 1;   //Signal that the servo signals have gone missing(no rx signal).
led_frequency = RC_LED_FREQUENCY_VAL_4HZ;

/****************************  SETUP THE PIN INTERRUPT  *************************************************/
wdt_disable();
#if F_CPU <= 8000000UL
wdt_enable(WDTO_60MS);
#else
wdt_enable(WDTO_30MS);
#endif

WDTCSR |= (1<<WDIE);
wdt_reset();

// Now we must disable the pin interrupt.
RC_PIN_INT_EN_REG &= (~(1<<RC_PIN_INT_EN_BIT));
//Now we must load the pin interrupt mask register.
RC_PIN_INT_MASK_REG = channel_mask;
//Clear any pin interrupt flag set.
RC_PIN_INT_FLAG_REG |= (1<<RC_PIN_INT_FLAG_BIT);
// Clear the pin interrupt ISR detection variable
pin_interrupt_detected = 0;
// Finally we can enable the pin interrupt again.
RC_PIN_INT_EN_REG |= (1<<RC_PIN_INT_EN_BIT);
// Take a snapshot of the servo pins in order to establish a starting point.

/*------------------------------------------------------------------------------------------------------*/
/*                               PPM OUTPUT AND LED INDICATION CONTROL                                  */
/*------------------------------------------------------------------------------------------------------*/
while(1)
    {

       // Here we decide if a re synchronization with the input is needed.
       if(servo_signals_lost)
        {
           get_pw_of_connected_channels(1);

        }else{
                get_pw_of_connected_channels(0);
             }

/*------------------------------------------------------------------------------------------------------*/
       // Finally we can control when the PPM generator will be on and off.
       led_counter++;
       if( led_counter >= led_frequency ){ led_counter = 0; TOGGLE_LED(); }
       if( channel_mask_buffer == 0  ) //IF ALL CHANNELS HAVE BEEN MEASURED...
        {
           tx_signal_lost = 0;
           if(servo_signals_lost) //IF PREVIOUSLY THE SERVO SIGNAL WAS LOST...
            {
              tx_signal_detected++;
              if(tx_signal_detected > RC_MAX_BAD_PPM_FRAMES)
               {
                 ppm_on();
                 servo_signals_lost = 0;
                 led_counter = 0;
                 led_frequency = RC_LED_FREQUENCY_VAL_4HZ;
               }
            }
        }
       else{  //IF NOT ALL CHANNELS HAVE BEEN MEASURED...
              tx_signal_detected = 0;
              if(servo_signals_lost == 0)
               {
		   tx_signal_lost++;
                   if(tx_signal_lost > RC_MAX_BAD_PPM_FRAMES)
                    {
                       servo_signals_lost = 1;
                       led_counter = 0;
                       led_frequency = RC_LED_FREQUENCY_VAL_1HZ;
#if defined(RC_USE_FAILSAFE) && RC_USE_FAILSAFE == 1
                       load_failsafe_values();
#else
                       ppm_off();
#endif
                    }
               } //end of if(servo_signals_lost == 0) statement.
           } //end of if( x > (channels_in_use/2)  ){...}else{...} statement.
    } //end of while(1) loop.

}
/********************************************************************************************************/
/*                                   INTERRUPT SERVICE ROUTINES                                         */
/********************************************************************************************************/
#if (__GNUC__ == 4 && __GNUC_MINOR__ == 2)
/*
I used this approach because AVR-gcc produces safe code which is far from optimized with a lot of overhead.
For GCC versions greater then 4.2.x global register variables get trashed during optimization
so i need to use normal ram variables instead.
The asm ISR code presented here needs the below variables to be exclusively allocated to predefined registers:

register volatile unsigned char  timer0_l8 asm("r2");
register volatile unsigned char  timer0_h8 asm("r3");
register volatile unsigned int   isr_time_stamp asm("r4");
register volatile unsigned char  pin_interrupt_detected asm("r6");
register volatile unsigned char  sreg_save asm("r7");
Also for clarity:
70-0x20 = TCNT0
59-0x20 = PCIFR and the fourth bit (3) is the PCIF2 flag.
53-0x20 = TIMER0 TIFR  and the first bit (0) is the OVF0 flag.
*/

ISR(TIMER0_OVF_vect, ISR_NAKED)
{
__asm__ __volatile__(
			"in	r7, __SREG__		\n\t"
			"inc	r3			\n\t"
			"sbis	59-0x20, 3		\n\t"
			"rjmp	.no_external_pin_int	\n\t"
	                "clr	r2			\n\t"
#if F_CPU <= 8000000UL
	                "inc	r2			\n\t"
#endif
			"movw	r4,r2			\n\t"
     			"mov	r6, r3			\n\t"
        	        "sbi	59-0x20, 3		\n\t"
		        ".no_external_pin_int:		\n\t"
			"out	__SREG__, r7		\n\t"
			"reti				\n\t"

                    ::);
/*
// C EQUIVALENT CODE
sreg_save = SREG;
timer0_h8++;
if( (RC_PIN_INT_FLAG_REG & (1<<RC_PIN_INT_FLAG_BIT)) )
 {
    timer0_l8 = TCNT0;
    isr_time_stamp = (timer0_h8<<8) + timer0_l8;
    pin_interrupt_detected = 1;
    RC_PIN_INT_FLAG_REG = (1<<RC_PIN_INT_FLAG_BIT);
 }
SREG = sreg_save;
*/
}

/********************************************************************************************************/

ISR(PCINT2_vect, ISR_NAKED)
{
__asm__ __volatile__(
	                "in	r2, 70-0x20		\n\t"
                        "in	r7,  __SREG__		\n\t"
	                "sbis	53-0x20, 0	     	\n\t"
 	                "rjmp	.no_timer0_ovf		\n\t"
	                "clr	r2			\n\t"
                        "inc	r3          		\n\t"
                        "sbi	53-0x20, 0   		\n\t"
                         ".no_timer0_ovf: 		\n\t"
                        "movw	r4,r2			\n\t"
                        "clr	r6          		\n\t"
                	"inc	r6			\n\t"
                	"out	__SREG__, r7		\n\t"
                 	"reti                 		\n\t"
	          ::);
/*
// C EQUIVALENT CODE
timer0_l8 = TCNT0;
sreg_save = SREG;
if( (RC_TIMER0_TIFR & (1<<TOIE0)) )
 {
    timer0_l8 = TCNT0;
    timer0_h8++;
    RC_TIMER0_TIFR = (1<<TOIE0);
 }
isr_time_stamp = (timer0_h8<<8) + timer0_l8;
pin_interrupt_detected = 1;
SREG = sreg_save;
//RC_PIN_INT_FLAG_REG = (1<<RC_PIN_INT_FLAG_BIT);

*/

}

#else

//For GCC versions greater then 4.2.x global register variables get trashed during optimization
//so i need to use normal ram variables instead. i don't use any register variables here.
ISR(TIMER0_OVF_vect, ISR_NAKED)
{
/*
In order to make the	ISR as fast and accurate it can be, i am forced to use more code but the execution is faster.
It would be nice to have an extra 16 bit timer but i don't, so i am forced to use tricks with an 8 bit timer.
*/
__asm__ __volatile__(
			"sbic	59-0x20, 3			\n\t"
			"rjmp	.external_pin_int0		\n\t"
			"push	r2				\n\t"
			"push	r3				\n\t"
			"in	r3, __SREG__			\n\t"
			"lds	r2, timer0_h8			\n\t"
			"inc	r2				\n\t"
     			"sts	timer0_h8, r2			\n\t"
			"out	__SREG__, r3			\n\t"
			"pop	r3				\n\t"
			"pop	r2				\n\t"
			"sbis	59-0x20, 3			\n\t"
			"rjmp	.no_external_pin_int		\n\t"
			"push	r24				\n\t"
			"lds	r24, timer0_h8			\n\t"
			"sts	(isr_time_stamp)+1, r24		\n\t"
         		"ldi	r24, 1				\n\t"
			"sts	isr_time_stamp, r24		\n\t"
     			"sts	pin_interrupt_detected, r24	\n\t"
        	        "sbi	59-0x20, 3			\n\t"
			"pop	r24				\n\t"
			".no_external_pin_int:			\n\t"
			"reti					\n\t"

		        ".external_pin_int0:			\n\t"
			"push	r2				\n\t"
			"push	r3				\n\t"
			"in	r3, __SREG__			\n\t"
			"lds	r2, timer0_h8			\n\t"
			"inc	r2				\n\t"
     			"sts	timer0_h8, r2			\n\t"
			"sts	(isr_time_stamp)+1, r2		\n\t"
         		"clr	r2				\n\t"
			"sts	isr_time_stamp, r2		\n\t"
         		"inc	r2				\n\t"
     			"sts	pin_interrupt_detected, r2	\n\t"
        	        "sbi	59-0x20, 3			\n\t"
			"out	__SREG__, r3			\n\t"
			"pop	r3				\n\t"
			"pop	r2				\n\t"
			"reti					\n\t"

                    ::);

}

/*
ISR(TIMER0_OVF_vect)
{
timer0_h8++;
if( (RC_PIN_INT_FLAG_REG & (1<<RC_PIN_INT_FLAG_BIT)) )
 {
    isr_time_stamp = (timer0_h8<<8);
    pin_interrupt_detected = 1;
    RC_PIN_INT_FLAG_REG = (1<<RC_PIN_INT_FLAG_BIT);
 }

return;
}
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

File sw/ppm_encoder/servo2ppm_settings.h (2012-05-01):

/*********************************************************************************************************
 Title  :   header file for the rc ppm encoder (servo2ppm_settings.h)
 Author:    Chris Efstathiou 
 E-mail:    hendrix at vivodinet dot gr
 Homepage:  ........................
 Date:      6/Feb/2010
 Compiler:  AVR-GCC with AVR-AS
 MCU type:  ATmega168 
 Comments:  This software is FREE. Use it at your own risk.
*********************************************************************************************************/

#ifndef SERVO2PPM_SETTINGS_H
#define SERVO2PPM_SETTINGS_H

/********************************************************************************************************/
/*                                  USER CONFIGURATION BLOCK START                                      */
/********************************************************************************************************/
/*
The cpu frequency is defined in the makefile, the below definition is used only if the cpu frequency
is not defined in the makefile.
*/

#ifndef F_CPU
#define F_CPU                         8000000UL        /* CPU CLOCK FREQUENCY */
#endif
/*
Those values are the failsafe servo values and the values for the non used channels
If for example you leave unconnected channel 7, the servo pulse of channel 7 in the PPM train
will be the failsafe value set below as "RC_FAILSAFE_CHANNEL_7" thus 1000 microseconds.
*/

#define RC_FAILSAFE_CHANNEL_1         1500UL
#define RC_FAILSAFE_CHANNEL_2         1500UL
#define RC_FAILSAFE_CHANNEL_3         1000UL
#define RC_FAILSAFE_CHANNEL_4         1500UL
#define RC_FAILSAFE_CHANNEL_5         1000UL
#define RC_FAILSAFE_CHANNEL_6         1000UL
#define RC_FAILSAFE_CHANNEL_7         1000UL
#define RC_FAILSAFE_CHANNEL_8         1000UL

/*
When signal is lost 1= ppm waveform remain on with failsafe values, 0= ppm waveform is off
For use with Paparazzi use "0", the autopilot has it's own failsafe values when PPM signal is lost.
The above failsafe values will kick in only if the servo inputs are lost which cannot happen with
a receiver with dsp processing that provides "hold" or "failsafe" features.
If the receiver only provides "hold" on the last good servo signals received  it is not suitable
for use with the Paparazzi autopilot as it will prohibit the autopilot entering the "AUTO2" or "HOME" mode.
If you use a receiver with failsafe ability then remember to set the failsafe value of the receiver
to 2000 microseconds for the "MODE" channel so the autopilot can go to "AUTO2" or "HOME" mode when the receiver
loose the tx signal. The servo signals on receivers like PCM, IPD and any receiver with servo hold AND failsafe
will not stop outputing servo pulses thus the encoder will never stop producing a PPM pulse train
except if the throttle channel is used as an indication by setting the "RC_LOST_CHANNEL" to a value above 0.
If you use the throttle channel as an indication that the TX signal is lost then:
RC_USE_FAILSAFE set to 0 means that the ppm output will be shut down and if you set
RC_USE_FAILSAFE  to 1 the ppm output will NOT shut down but it will now output the failsafe values
defined above.
*/
#define RC_USE_FAILSAFE               0

/*
The channel number (1,2,3...7,8) that will be used as a receiver ready indicator.
If set above 0 then this channel should be always connected otherwise
the PPM output will not be enabled as the ppm encoder will wait for ever for this channel
to produce a valid servo pulse.
If 0 then the first connected channel going from channel 1 to 8 will be used, in other words
which ever connected channel comes on first it will indicate that the receiver is operational.
The detection of all connected channels is independent of this setting, this channel
is used as an indication that the receiver is up and running only.
*/
#define RC_RX_READY_CHANNEL           0     /* 0 = No channel will be exclusively checked. */

/*
The default value for the rc signal lost indicator channel and it's threshold value in microseconds .
If the value is above 1500 microseconds then when the signal lost indicator channel servo pulse exceeds
RC_LOST_THRESHOLD then the ppm output will be shut down.
If the value is below 1500 microseconds then when the signal lost indicator channel servo pulse gets lower than
RC_LOST_THRESHOLD then the ppm output will be shut down.
If the RC_USE_FAILSAFE is set to 1 then the ppm output will not stop producing pulses but now
the ppm wavetrain will contain the failsafe values defined in the beginning of this file.
The RC_LOST_CHANNEL must be a value from 1 to 8.
0 = the function is disabled. BE CAREFULL, 0 IS A VERY DANGEROUS OPTION !!!
*/
#define RC_LOST_CHANNEL               3      /* Defaul is the throttle channel. You can use any channel. */
#define RC_LOST_THRESHOLD             2025   /* Any value below 1300 or above 1700 microseconds. */
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

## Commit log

2012-05-01 first addition of original servo2ppm_v4_3_final_7-feb-2010.zip file from hendrix, note that crlf endings were automatically converted to lf endings by git. From the original the only major change was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
    [ppm_encoder_402.brd, ppm_encoder_402.sch, ppm_encoder_402_crystal.brd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]
2012-05-01 fixed two small bugs in ppm encoder (index reversal and wrong greater than sign), added defineable ppm filter window size, cleaned up formatting
    [ppm_encoder_v4_3.c, servo2ppm_settings.h]
